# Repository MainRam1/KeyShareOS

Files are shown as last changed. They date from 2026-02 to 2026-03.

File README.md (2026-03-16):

# KeyShare

An open-source 9-key programmable macropad built from the ground up — custom PCB designed in KiCad, CircuitPython firmware running on the RP2040, and a native macOS companion app written in Swift. Assign keyboard shortcuts, launch apps, type text, switch desktops, control media, open URLs, trigger app menu actions, or chain actions into multi-step macros — all from a compact 3x3 mechanical key grid that auto-switches profiles based on your active application or website.

## Features

- **8 action types** -- keyboard shortcuts, app launch, text typing, desktop switching, media control, open url, app menu actions, multi-step macros
- **Unlimited profiles** -- organize keys by task or project
- **Auto-switch by app** -- profiles change automatically based on the active application
- **Auto-switch by website** -- profiles change based on the active tab in Safari or Chrome
- **App menu actions** -- browse and trigger any menu bar item in any running app, with keyboard shortcut fallback
- **Visual key editor** -- drag-and-drop 3x3 grid in the preferences window
- **OSD overlay** -- on-screen display when the active profile changes
- **Menu bar utility** -- lives in the menu bar with no Dock icon
- **Hot-plug support** -- detects device connect/disconnect and recovers after sleep
- **Config file watching** -- edits made in a text editor are picked up immediately
- **Profile import/export** -- share profiles as JSON files
- **Custom PCB** -- open-source KiCad design with manufacturing-ready Gerber files

## How It Works

Press a Cherry MX key on the macropad → the RP2040 firmware sends a JSON message over USB serial → the macOS menu bar app receives it and executes the configured action. The app monitors your active application and browser tab, automatically switching profiles so your keys always match what you're working in. A bidirectional serial protocol handles device detection, hot-plug recovery, and sleep/wake reconnection.

## Requirements

| Component | Minimum |
|---|---|
| macOS | 13.0 (Ventura) |
| Microcontroller | Raspberry Pi Pico (RP2040) |
| Switches | 9 x Cherry MX compatible |
| Firmware runtime | CircuitPython 9.x |

## Hardware

The `Hardware/` directory contains the complete KiCad project for a custom 2-layer PCB:

- **Schematic & PCB layout** -- KiCad 9.0 project files
- **Gerber files** -- manufacturing-ready, located in `Hardware/Gerbers/`
- **BOM** -- `Hardware/MacroPad.csv` with all components listed

Key components: RP2040 microcontroller, W25Q16 16Mbit SPI flash, USB-C connector with ESD protection, AP2112K-3.3 voltage regulator, and 9 Cherry MX compatible switch footprints.

## Quick Start

1. **Flash firmware** -- install [CircuitPython 9.x](https://circuitpython.org/board/raspberry_pi_pico/) on the Pico, then copy `firmware/code.py` and `firmware/boot.py` to the `CIRCUITPY` drive.
2. **Download the app** -- grab the latest `.zip` from [GitHub Releases](../../releases), unzip, and move `KeyShare.app` to `/Applications`.
3. **Launch** -- open the app. It appears in the menu bar.
4. **Grant Accessibility permission** -- the first-launch onboarding will prompt you. Go to **System Settings > Privacy & Security > Accessibility** and enable KeyShare.
5. **Plug in the macropad** -- the app detects it automatically.

## Building from Source

```bash
# Install xcodegen (once)
brew install xcodegen

# Generate the Xcode project
cd MacroApp
xcodegen generate

# Build
xcodebuild -project KeyShare.xcodeproj -scheme KeyShare -configuration Release build
```

The built `.app` bundle is ad-hoc signed -- no Apple Developer ID required.

## Firmware Setup

1. Hold the BOOTSEL button on the Pico and plug it in via USB.
2. Copy the CircuitPython 9.x `.uf2` file to the `RPI-RP2` drive.
3. After the Pico reboots, copy the firmware files:

```bash
cp firmware/code.py /Volumes/CIRCUITPY/
cp firmware/boot.py /Volumes/CIRCUITPY/
```

The Pico will reboot and begin communicating over USB serial.

## Configuration

The app stores its config at:

```
~/Library/Application Support/KeyShare/config.json
```

You can edit profiles and key bindings through the preferences window or by editing the JSON file directly. Changes are picked up automatically.

## License

[MIT](LICENSE)

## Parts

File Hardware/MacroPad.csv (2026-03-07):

Reference | Qty | Value | DNP | Exclude from BOM | Exclude from Board | Footprint | Datasheet
C1,C2 | 2 | 15pF |  |  |  |  | ~
C3,C5,C7,C10,C11,C12,R7 | 7 | 100nF |  |  |  |  | ~
C4,C6 | 2 | 10uF |  |  |  |  | ~
C8,C9 | 2 | 1uF |  |  |  |  | ~
F1 | 1 | 500mA |  |  |  |  | ~
J1 | 1 | USB_C_Receptacle_USB2.0_16P |  |  |  |  | https://www.usb.org/sites/default/files/documents/usb_type-c.zip
R1 | 1 | 10k |  |  |  |  | ~
R2,R3 | 2 | 5.1k |  |  |  |  | ~
R4,R5 | 2 | 27R |  |  |  |  | ~
R6 | 1 | 10K |  |  |  |  | ~
SW1,SW2,SW3,SW4,SW5,SW6,SW7,SW8,SW9,SW10,SW11 | 11 | SW_Push |  |  |  |  | ~
U1 | 1 | RP2040 |  |  |  | Package_DFN_QFN:QFN-56-1EP_7x7mm_P0.4mm_EP3.2x3.2mm | https://datasheets.raspberrypi.com/rp2040/rp2040-datasheet.pdf
U2 | 1 | W25Q16JVSS |  |  |  | Package_SO:SOIC-8_5.3x5.3mm_P1.27mm | https://www.winbond.com/hq/support/documentation/levelOne.jsp?__locale=en&DocNo=DA00-W25Q16JV.1
U3 | 1 | AP2112K-3.3 |  |  |  | Package_TO_SOT_SMD:SOT-23-5 | https://www.diodes.com/assets/Datasheets/AP2112.pdf
U4 | 1 | USBLC6-2SC6 |  |  |  | Package_TO_SOT_SMD:SOT-23-6 | https://www.st.com/resource/en/datasheet/usblc6-2.pdf
Y1 | 1 | 12Mhz |  |  |  |  | ~

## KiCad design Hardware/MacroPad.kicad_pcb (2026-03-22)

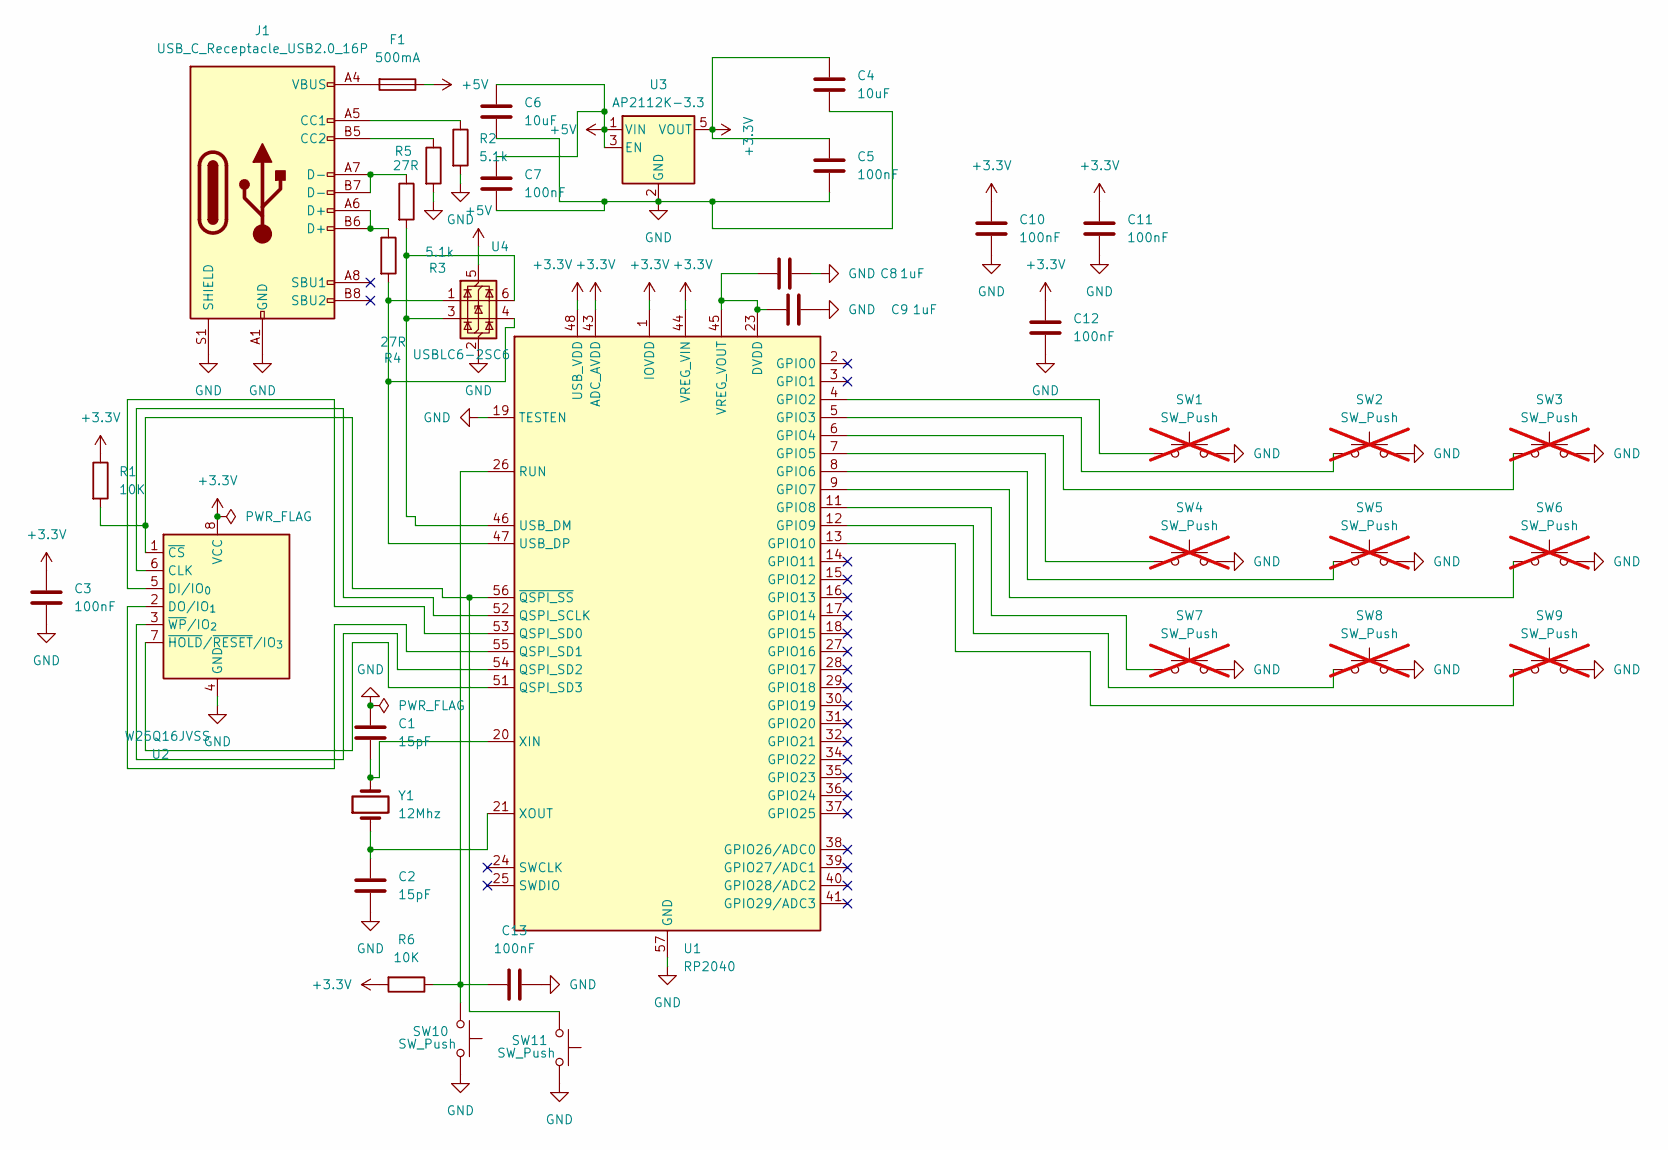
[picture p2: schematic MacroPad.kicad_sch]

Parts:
C1, C2: 15pF; C_0402_1005Metric; MPN GRM1555C1H150JA01D
C3, C5, C7, C10, C11, C12, C13: 100nF; C_0402_1005Metric; MPN CL05B104KO5NNNC
C4, C6: 10uF; C_0805_2012Metric; MPN CL21A106KAYNNNE
C8, C9: 1uF; C_0402_1005Metric; MPN CL05A105KA5NQNC
F1: 500mA; Fuse_1206_3216Metric; MPN 1206L050YR
J1: USB_C_Receptacle_USB2.0_16P; USB_C_Receptacle_GCT_USB4085; MPN USB4085-GF-A
R1, R6: 10K; R_0402_1005Metric; MPN RC0402FR-0710KL
R2, R3: 5.1k; R_0402_1005Metric; MPN RC0402FR-075K1L
R4, R5: 27R; R_0402_1005Metric; MPN RC0402FR-0727RL
SW1, SW2, SW3, SW4, SW5, SW6, SW7, SW8, SW9: SW_Push; SW_Cherry_MX_1.00u_PCB; not fitted
SW10, SW11: SW_Push; SW_SPST_PTS810; MPN PTS810 SJK 250 SMTR LFS
U1: RP2040; QFN-56-1EP_7x7mm_P0.4mm_EP3.2x3.2mm; MPN SC0914(13)
U2: W25Q16JVSS; SOIC-8_5.3x5.3mm_P1.27mm; MPN W25Q16JVSSIQ
U3: AP2112K-3.3; SOT-23-5; MPN AP2112K-3.3TRG1
U4: USBLC6-2SC6; SOT-23-6; MPN USBLC6-2SC6
Y1: 12Mhz; Crystal_SMD_3225-4Pin_3.2x2.5mm; MPN ABM8-272-T3

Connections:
+3.3V: C3.1, C4.1, C5.1, C10.1, C11.1, C12.1, R1.1, R6.2, U1.1 (IOVDD), U1.10 (IOVDD), U1.22 (IOVDD), U1.33 (IOVDD), U1.42 (IOVDD), U1.43 (ADC_AVDD), U1.44 (VREG_VIN), U1.48 (USB_VDD), U1.49 (IOVDD), U2.8 (VCC), U3.5 (VOUT)
+5V: C6.1, C7.1, F1.1, U3.1 (VIN), U3.3 (EN), U4.5 (VBUS)
GND: C1.1, C2.2, C3.2, C4.2, C5.2, C6.2, C7.2, C8.1, C9.1, C10.2, C11.2, C12.2, C13.2, J1.A1 (GND), J1.A12 (GND), J1.B1 (GND), J1.B12 (GND), J1.S1 (SHIELD), R2.2, R3.2, SW1.2, SW2.2, SW3.2, SW4.2, SW5.2, SW6.2, SW7.2, SW8.2, SW9.2, SW10.2, SW11.2, U1.19 (TESTEN), U1.57 (GND), U2.4 (GND), U3.2 (GND), U4.2 (GND)
unnamed: F1.2, J1.A4 (VBUS), J1.A9 (VBUS), J1.B4 (VBUS), J1.B9 (VBUS)
unnamed: J1.A5 (CC1), R2.1
unnamed: J1.B5 (CC2), R3.1
unnamed: J1.A6 (D+), J1.B6 (D+), R4.1
unnamed: J1.A7 (D-), J1.B7 (D-), R5.1
unnamed: SW1.1, U1.4 (GPIO2)
unnamed: SW2.1, U1.5 (GPIO3)
unnamed: SW3.1, U1.6 (GPIO4)
unnamed: SW4.1, U1.7 (GPIO5)
unnamed: SW5.1, U1.8 (GPIO6)
unnamed: SW6.1, U1.9 (GPIO7)
unnamed: SW7.1, U1.11 (GPIO8)
unnamed: SW8.1, U1.12 (GPIO9)
unnamed: SW9.1, U1.13 (GPIO10)
unnamed: U1.52 (QSPI_SCLK), U2.6 (CLK)
unnamed: U1.53 (QSPI_SD0), U2.5 (DI/IO_{0})
unnamed: U1.55 (QSPI_SD1), U2.2 (DO/IO_{1})
unnamed: U1.54 (QSPI_SD2), U2.3 (~WP/IO_{2})
unnamed: U1.51 (QSPI_SD3), U2.7 (~HOLD/~RESET/IO_{3})
unnamed: C13.1, R6.1, SW10.1, U1.26 (RUN)
unnamed: R5.2, U1.46 (USB_DM), U4.3 (I/O2), U4.6 (I/O1)
unnamed: R4.2, U1.47 (USB_DP), U4.1 (I/O1), U4.4 (I/O2)
unnamed: C8.2, C9.2, U1.23 (DVDD), U1.45 (VREG_VOUT), U1.50 (DVDD)
unnamed: C1.2, U1.20 (XIN), Y1.2
unnamed: C2.1, U1.21 (XOUT), Y1.1
unnamed: R1.2, SW11.1, U1.56 (~QSPI_SS), U2.1 (~CS)

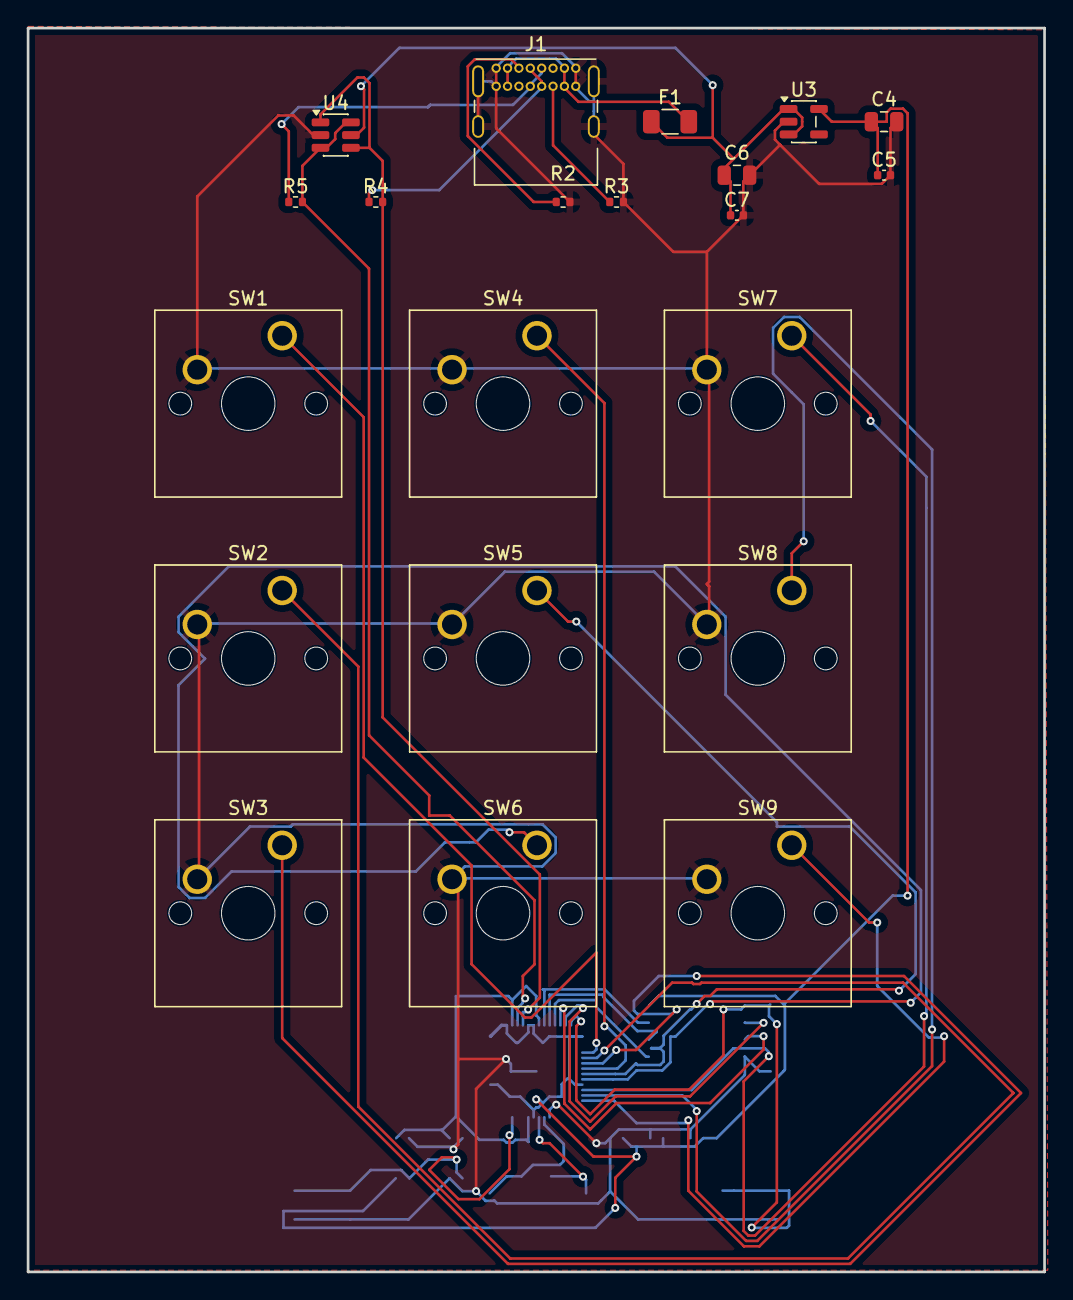
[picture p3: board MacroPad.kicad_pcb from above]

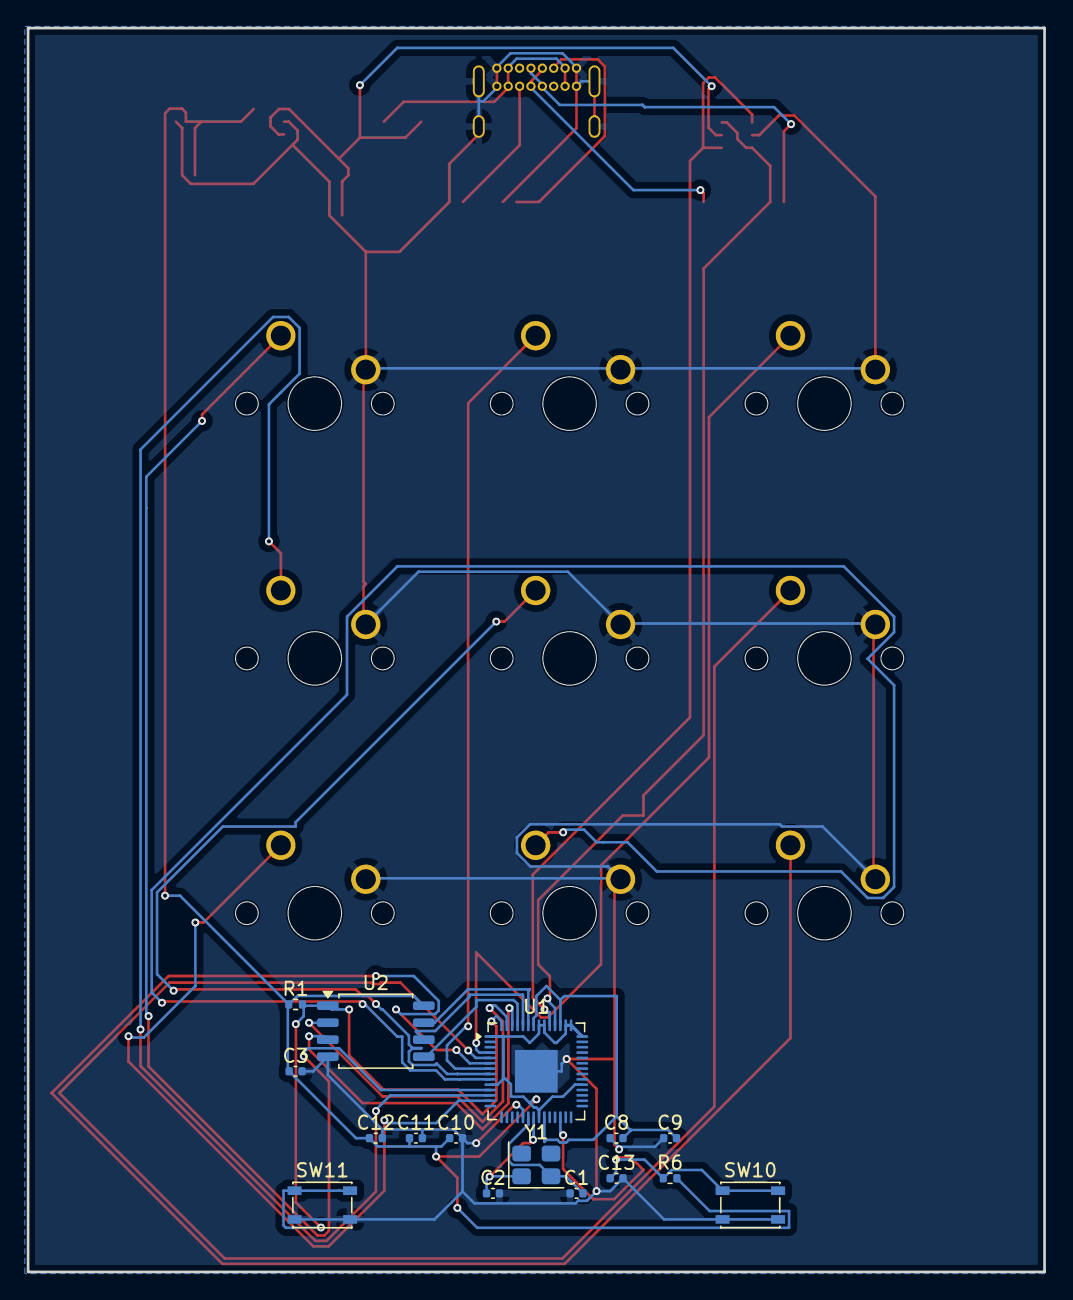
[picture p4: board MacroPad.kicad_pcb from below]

Board: 2 copper layers, 76.0 x 93.0 mm, 37 parts (16 on the bottom side), 29 nets.

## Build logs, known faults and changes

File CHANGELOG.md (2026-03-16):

# Changelog

All notable changes to this project will be documented in this file.

## [5.0.0] - 2026-03-15

### Added
- Website auto-switch: profiles change based on the active tab in Safari or Chrome
- App menu actions: browse and trigger any menu bar item via AXUIElement traversal, with keyboard shortcut fallback
- BrowserURLMonitor: AXObserver-based browser tab detection with debounced domain resolution
- Menu browser UI for selecting menu items in the key config editor
- Website auto-switch rules UI in settings
- NSAppleEventsUsageDescription for browser URL queries

### Changed
- AppSwitchMonitor now supports website match priority over app match
- Profile deletion cleans up website switch rules
- Refactored AppActionAction into separate files for SwiftLint compliance

## [1.0.0] - 2026-02-18

### Added
- 9-key macropad firmware (CircuitPython) with USB serial communication
- macOS companion app (menu bar utility)
- 7 action types: keyboard shortcuts, app launch, text typing, desktop switching, media control, macros, open url
- Profile system with unlimited profiles
- Auto-switch profiles by active application
- Visual 3x3 key grid editor in preferences
- OSD overlay on profile switch
- First-launch onboarding for Accessibility permission
- Device hot-plug detection and sleep/wake recovery
- Config file watching for external edits
- Profile import/export
- GitHub Actions CI/CD pipeline

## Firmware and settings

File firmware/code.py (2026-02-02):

"""Macro Firmware — code.py

Main firmware for the 9-key macropad on Raspberry Pi Pico.
Scans 9 Cherry MX switches, sends JSON key events over USB CDC serial,
and receives host messages (ack, profile_changed).

Architecture: State machine with dependency injection for testability.
"""

import board
import gc
import json
import keypad
import time
import usb_cdc

# --- Constants ---

FIRMWARE_VERSION = "0.1.0"
PROTOCOL_VERSION = 1
NUM_KEYS = 9
HEARTBEAT_INTERVAL_S = 5.0
READY_RETRY_INTERVAL_S = 3.0

# GPIO pin assignments — order determines key numbering (0-indexed internally).
# Key 1 = GP2, Key 2 = GP3, ..., Key 9 = GP10.
KEY_PINS = (
    board.GP2,   # Key 1
    board.GP3,   # Key 2
    board.GP4,   # Key 3
    board.GP5,   # Key 4
    board.GP6,   # Key 5
    board.GP7,   # Key 6
    board.GP8,   # Key 7
    board.GP9,   # Key 8
    board.GP10,  # Key 9
)


# --- State Machine ---

class FirmwareState:
    """Firmware operational states."""
    INITIALIZING = "initializing"
    WAITING_FOR_HOST = "waiting_for_host"
    RUNNING = "running"
    ERROR = "error"


# --- Serial Communication ---

class SerialComm:
    """Handles all serial communication with the host.

    Single exit point for outbound messages (json.dumps only called here).
    Accepts an injected serial port for testability.
    """

    def __init__(self, serial_port):
        self._port = serial_port
        self._read_buffer = bytearray()

    def send(self, message_dict):
        """Send a JSON message terminated by newline. Single serialization point."""
        if self._port is None:
            return
        try:
            self._port.write((json.dumps(message_dict) + "\n").encode())
        except OSError:
            pass  # Host disconnected — handled by state machine

    def send_key_press(self, key_number):
        """Send a key press event. key_number is 1-indexed (user-facing)."""
        self.send({"type": "key_press", "key": key_number})

    def send_key_release(self, key_number):
        """Send a key release event. key_number is 1-indexed (user-facing)."""
        self.send({"type": "key_release", "key": key_number})

    def send_ready(self):
        """Send device ready message on startup/reconnection."""
        self.send({
            "type": "ready",
            "protocol": PROTOCOL_VERSION,
            "firmware": FIRMWARE_VERSION,
            "keys": NUM_KEYS,
        })

    def send_heartbeat(self):
        """Send heartbeat to indicate device is alive."""
        self.send({"type": "heartbeat"})

    def read_message(self):
        """Non-blocking read of a single JSON message from host.

        Returns parsed dict if a complete message is available, None otherwise.
        Accumulates partial reads in an internal buffer.
        """
        if self._port is None or self._port.in_waiting == 0:
            return None

        # Read available bytes into buffer
        incoming = self._port.read(self._port.in_waiting)
        if incoming:
            self._read_buffer.extend(incoming)

        # Look for a complete line (newline-terminated JSON)
        newline_pos = self._read_buffer.find(b"\n")
        if newline_pos == -1:
            return None

        # Extract the line and remove it from buffer
        line = self._read_buffer[:newline_pos]
        self._read_buffer = self._read_buffer[newline_pos + 1:]

        try:
            return json.loads(line)
        except (ValueError, UnicodeError):
            return None  # Malformed JSON — discard


# --- Key Scanner ---

class KeyScanner:
    """Wraps keypad.Keys for the 9-key macropad.

    Uses internal pull-ups with value_when_pressed=False
    (Cherry MX switches pull to GND when pressed).
    """

    def __init__(self, pins):
        self._keys = keypad.Keys(
            pins=pins,
            value_when_pressed=False,
            pull=True,
            interval=0.020,  # 20ms debounce (Cherry MX bounces <5ms)
            max_events=64,
        )
        self._event = keypad.Event()

    @property
    def events(self):
        """Access the event queue."""
        return self._keys.events

    def get_event(self):
        """Get the next key event without allocating.

        Returns (key_number_1indexed, is_pressed) or None.
        """
        if self._keys.events.get_into(self._event):
            # Convert 0-indexed to 1-indexed (user-facing key numbers)
            return (self._event.key_number + 1, self._event.pressed)
        return None


# --- Main Firmware ---

class MacropadFirmware:
    """Main firmware state machine.

    Coordinates key scanning, serial communication, and heartbeat timing.
    All dependencies are injected for testability.
    """

    def __init__(self, key_scanner, serial_comm):
        self._state = FirmwareState.INITIALIZING
        self._scanner = key_scanner
        self._serial = serial_comm
        self._last_heartbeat = 0.0
        self._last_ready_time = 0.0
        self._host_connected = False

    def run(self):
        """Main loop. Each state has exactly one handler method."""
        self._state = FirmwareState.WAITING_FOR_HOST
        self._serial.send_ready()
        now = time.monotonic()
        self._last_heartbeat = now
        self._last_ready_time = now

        while True:
            if self._state == FirmwareState.WAITING_FOR_HOST:
                self._handle_waiting()
            elif self._state == FirmwareState.RUNNING:
                self._handle_running()
            elif self._state == FirmwareState.ERROR:
                self._handle_error()

            gc.collect()

    def _handle_waiting(self):
        """Wait for host acknowledgment before processing keys."""
        msg = self._serial.read_message()
        if msg and msg.get("type") == "ack":
            self._host_connected = True
            self._state = FirmwareState.RUNNING
            return

        # Re-send ready periodically so the host can ack even if it
        # missed the first one (e.g. app launched after device boot,
        # or reconnection after unplug/replug).
        now = time.monotonic()
        if now - self._last_ready_time >= READY_RETRY_INTERVAL_S:
            self._serial.send_ready()
            self._last_ready_time = now

        # Still send heartbeats while waiting
        self._check_heartbeat()

        # Drain key events to prevent queue overflow while waiting
        while self._scanner.get_event() is not None:
            pass

    def _handle_running(self):
        """Process key events and host messages."""
        # Process all pending key events
        event = self._scanner.get_event()
        while event is not None:
            key_number, is_pressed = event
            if is_pressed:
                self._serial.send_key_press(key_number)
            else:
                self._serial.send_key_release(key_number)
            event = self._scanner.get_event()
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

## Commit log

2026-02-02 Commit 2: Getting the Raspberry Pi Pico firmware ready
2026-02-15 Commit 11: Profile Switching and auto-switch
2026-03-07 Commit 26: New Custom PCB
    [MacroPad-B_Cu.gbr, MacroPad-B_Mask.gbr, MacroPad-B_Paste.gbr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]
2026-03-16 Commit 31: profile auto-switch by website domain, menu-driven app actions
2026-03-22 Commit 35: Updated Schematic and PCB
    [MacroPad.kicad_pcb, MacroPad.kicad_sch]
